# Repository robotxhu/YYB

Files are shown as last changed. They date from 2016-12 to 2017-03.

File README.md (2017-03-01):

# 机器人足球协会摇摇棒PCB

@(机器人足球协会)[摇摇棒|Arduino|电子制作]

**摇摇棒**是一款基于arduino nano 的电子小制作，主要用于机器人足球协会期末制作，在整个制作过程中历经三代开发，从第一版需要额外购买下载器和使用一节锂电池，到第二版更换为两节7号电池，和添加 `CH340G` 去掉下载器。第三版添加自动下载功能，修正以上两版三极管的错误使用，预留晶振焊盘，`CH340G`和`CH340B`可通用。
 
- **加深arduino理解** ：协会成员对arduino的理解
- **锻炼焊接技术** ：锻炼协会成员的焊工
- **炫酷的灯光效果** ：通过编程创造炫酷的灯光效果

-------------------

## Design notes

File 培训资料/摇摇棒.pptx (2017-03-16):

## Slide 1

摇摇棒

机器人足球协会

Happiness is about having each tiny wish come true.

Z_Q

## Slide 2

出场秀

程序&数据

Teach you how to add your images into the board and how to make images

Show you some images

CONTENTS

Show the board how to work

原理图

Now ! show you heart

个人秀

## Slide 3

01

Part One

机足

摇摇棒演示

检测摇摇棒是否正常工作

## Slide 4

02

Part Two

机足

原理图

Click me to find the treasure

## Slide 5

03

Part Three

机足

修改示例程序

There is a great software open the demo

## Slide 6

04

Part Four

Last

Let me see your lights

Use your hands to create beautiful things

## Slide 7

THANK Y U

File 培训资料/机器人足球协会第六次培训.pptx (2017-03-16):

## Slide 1

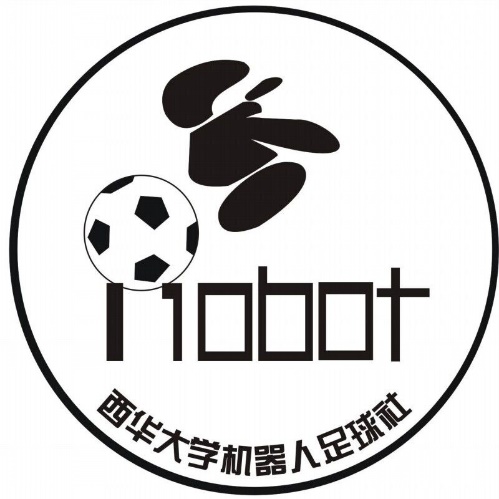
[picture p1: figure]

机器人足球协会第六次培训

Arduino与Processing互动编程

## processing简单入门

- Processing是一种具有革命前瞻性的新兴计算机语言，它的概念是在电子艺术的环境下介绍程序语言，并将电子艺术的概念介绍给程序设计师 (http://baike.baidu.com/view/170222.htm)。它是 Java 语言的延伸，并支持许多现有的 Java 语言架构，不过在语法 (syntax) 上简易许多，并具有许多贴心及人性化的设计。Processing 可以在 Windows、MAC OS X、MAC OS 9 、Linux 等操作系统上使用。

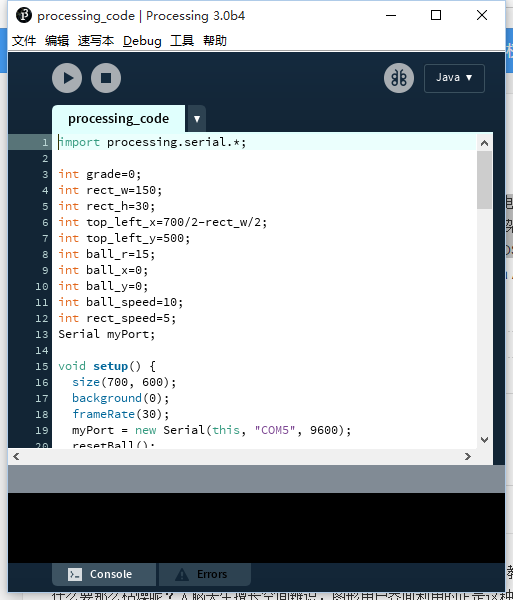
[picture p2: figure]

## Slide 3

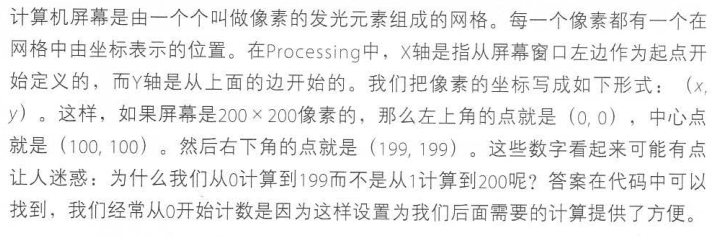
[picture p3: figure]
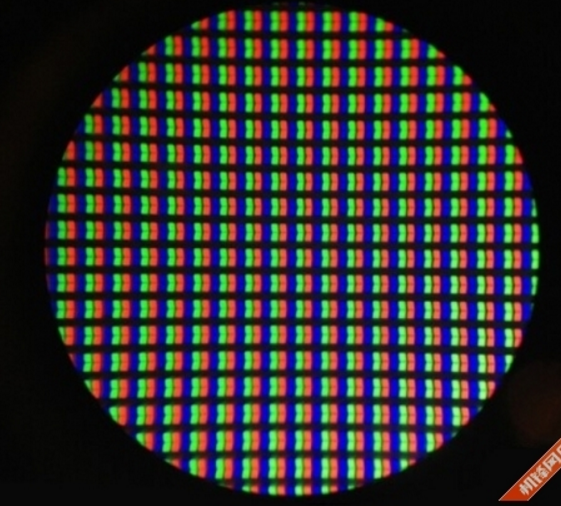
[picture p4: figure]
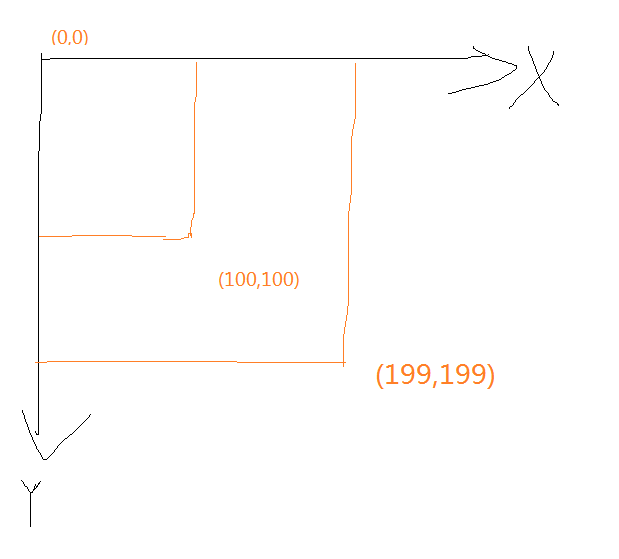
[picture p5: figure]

## 灰度颜色原理

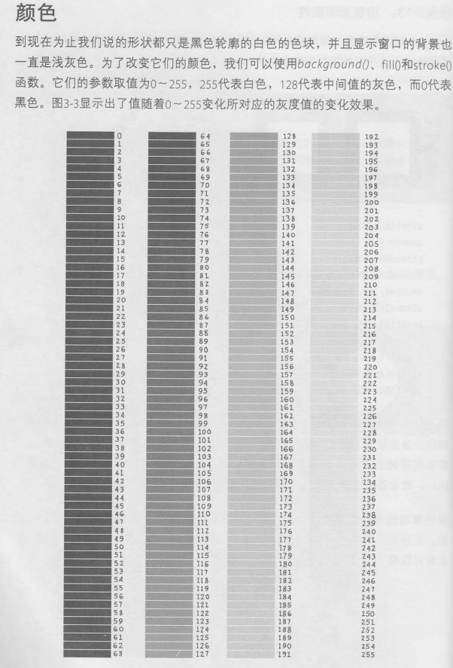
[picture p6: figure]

## 彩色绘图原理-------三基色原理

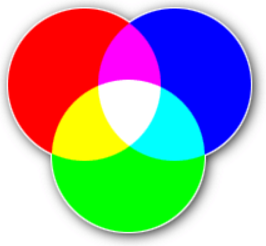
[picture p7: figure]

红绿蓝三基色

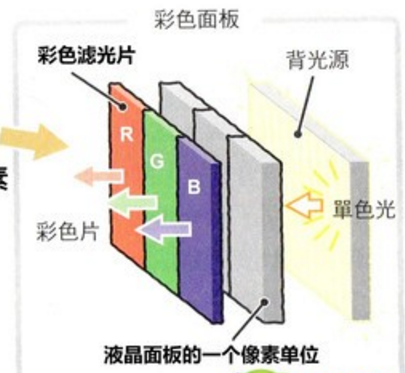
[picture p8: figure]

液晶显示原理

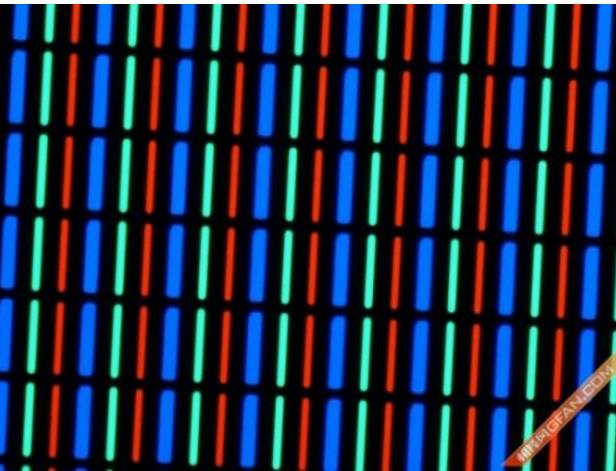
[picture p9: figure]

显示器放大像素点

## 画图原理

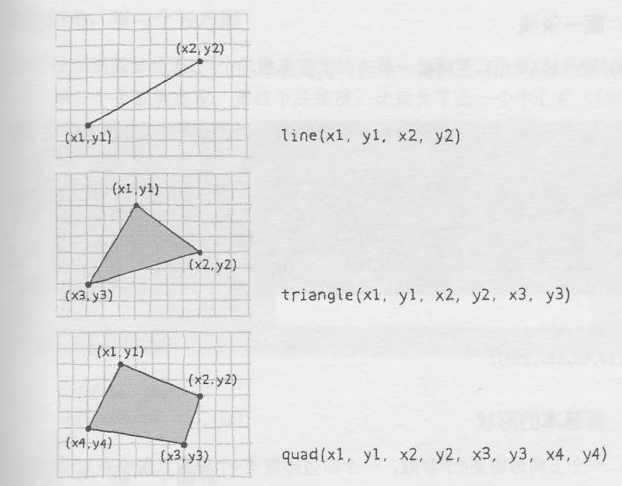
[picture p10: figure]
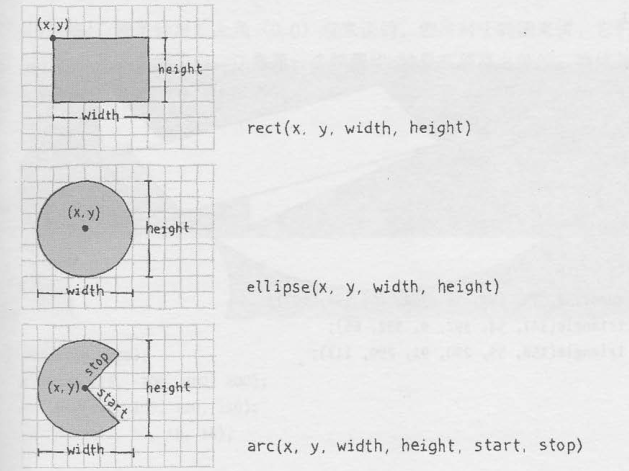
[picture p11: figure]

## 绘图函数

- size(200, 100); //设置窗口大小
- width，height //窗口的大小，无需定义可以直接使用
- background(color); //设置背景的颜色
- fill(color); //设置填充颜色
- random(a,b)； //产生a~b的随机数

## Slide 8

- ellipse(a, b, c, d)； //画椭圆函数
- a float: 圆心x坐标
- b float:圆心y坐标
- c float: 椭圆的宽度d float: 椭圆的高度

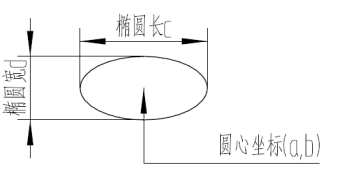
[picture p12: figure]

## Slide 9

- rect(a, b, c, d)； //绘制矩形函数
- a float: 矩阵左上角的x坐标
- b float:矩阵左上角的y坐标
- c float: 矩形的宽度
- d float: 矩形高度

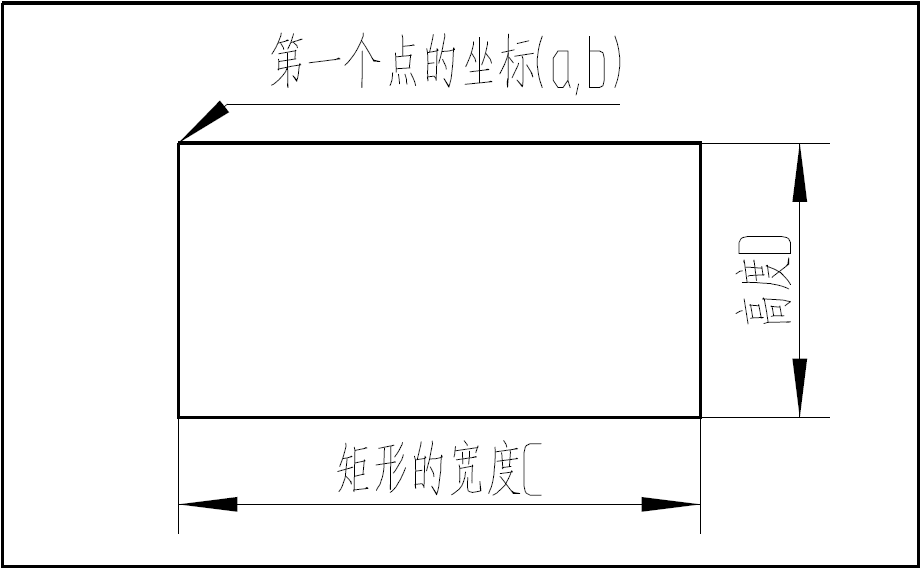
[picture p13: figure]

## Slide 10

- 显示文字
- textSize(32); //设置字体大小
- text(String, x, y);
- String : 要显示的字符串
- x,y:文字的位置坐标

## Processing和单片机通讯语句

- processing串口通信
- import processing.serial.*; //就像c语言里添加头文件
- Serial myPort; //定义一个串口；
- myPort = new Serial(this, “COM*”, 9600); //串口初始化
- myPort.available() //检测串口是否有数据要接收
- command = myPort.read(); //接收数据，存入到 command中

## processing串口示例代码

- import processing.serial.*;
- Serial myPort;
- void setup(){
  - myPort = new Serial(this, "COM5", 9600);
- }
- void draw(){
  - if (myPort.available()>0){
    - int command = myPort.read();
    - println(command);
  - }
- }

## arduino串口使用

- Serial.begain(9600);//初始化串口，设置通信速度为9600
- Serial.print(value); //发送数据value
- a=Serial.read(); //接收数据，并返回的a中
- Serial.available(); //判断是否有数据需要接收

int incomingByte = 0; // for incoming serial data
void setup() {
Serial.begin(9600); // opens serial port, sets data rate to 9600 bps
}
void loop() { // send data only when you receive data:
if (Serial.available() > 0) {
incomingByte = Serial.read(); // read the incoming byte:
Serial.print("I received: "); // say what you got:
Serial.println(incomingByte, DEC);
}
}

## 打印D2口返回的数据

- int a;
- void setup(){
  - pinMode(2,INPUT);
  - Serial.begin(9600);
- }
- void loop(){
  - a=digitalRead(2);
  - Serial.println(a);
- }

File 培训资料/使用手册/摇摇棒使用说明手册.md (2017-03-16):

#摇摇棒使用说明手册
[TOC]
##原理图


##代码调试
###流水灯
>通过流水灯代码的调试，可观察到三十二个灯顺序循环闪烁，同时可以检查摇摇棒是否正常工作。
```cpp
void setup() {
  // 初始化引脚
  for (int i = 2; i < 14; i++)
  {
    pinMode(i, OUTPUT);
  }
}

void loop() {
  // 全亮测试
  for (int i = 2; i < 14; i++)
  {
    digitalWrite(i, LOW);
  }
  // 延时
  delay(5000);
  // 全灭后再流水灯测试
  for (int i = 10; i < 14; i++)
  {
    digitalWrite(i, HIGH);
  }
  // 流水灯测试
  for (char i = 13; i >= 10; i--)
  {
    digitalWrite(i, LOW);
    for (char t = 2; t < 10; t++)
    {
      digitalWrite(t, LOW );
      delay(500);
      digitalWrite(t, HIGH );
    }
    digitalWrite(i, HIGH);
  }
}
```
###取模软件使用
>下载取模软件*PCtoLCD2002*，按照下图进行相应配置。主界面中文本框内的十六进制数组便是取出的字模。

>配置字高和字宽 点击齿轮图标 进入配置字模界面

>配置字模软件

>复制方框中的数据到yybqm.h中数组中

###显示字符
>1、改变 MAX_FRAEAM的值，有三个画面，MAX_FRAEAM后面值为2，四个画面，值为3以此类推。2、在switch case里面按照前面的格式添加一个新的case。3、yybqm.h中新建一个数组，在将之前在取模软件取好的模复制粘贴到yybqm.h中新建的数组里面。注意改变logo 。
```cpp

#include "yybqm.h"
#define DELAY_US 15
int frame = 0, x = 0, y = 0, len = 0;
char MAX_FRAEAM = 2;
void led(const char  a);
void displays(const char  b[]/*,int len*/);
void DELAY(int ms);

void setup() {
  pinMode(A1, INPUT_PULLUP);
  pinMode(A0, INPUT);
  // 初始化引脚
  for (int i = 2; i < 14; i++) {
    pinMode(i, OUTPUT);
    digitalWrite(i, HIGH);
  }
}

void frame_select() {
  DELAY(8);
  digitalRead(A0) == LOW ? frame ++  : frame = frame;
  frame > 2 ? frame = 0 : frame = frame;
}

void state() {
  DELAY(2);
  digitalWrite(A1, LOW);
}

void loop() {
  if (digitalRead(A1)) {
    switch (frame) {
      case 0:
        len = sizeof(logo1) / sizeof(logo1[0]);
        displays(logo1);
        break;
      case 1:
        len = sizeof(logo2) / sizeof(logo2[0]);
        displays(logo2);
        break;
      case 2:
        len = sizeof(logo3) / sizeof(logo3[0]);
        displays(logo3);
        break;
      default:
        len = sizeof(logo1) / sizeof(logo1[0]);
        displays(logo1);
    }
  }
  state();
  frame_select();
}

void led(const char  a) {
  for (int i = 2; i < 10; i++) {
    digitalWrite(i, bitRead(a, 9 - i));
  }
}

void displays(const char  b[]) {
  if (digitalRead(A1) == HIGH) {
    delay(20);
    if (digitalRead(A1) == HIGH) {
      for (x = 0; x < len ; x += 4) {
        for (y = 3; y >= 0; y--) {
          led(pgm_read_byte(&(b[x - y + 3 ])));
          digitalWrite(y + 10, LOW);
          delayMicroseconds(DELAY_US);
          digitalWrite(y + 10, HIGH);
        }
      }
    }
  }
}

void DELAY(int ms) {
  while (ms--) {
    for (int i = 0; i < 330; i++) {}
  }
}
```
>点击IDE的右上角箭头三角形，新建标签，以yybqm.h为名的头文件。
```cpp
#include <avr/pgmspace.h>

const char logo1[] PROGMEM = {     /*机器人足球*/
  0xFF, 0xFF, 0xFF, 0xFF, 0xFF, 0xFF, 0xFF, 0xFF, 0xFF, 0xFF, 0xFF, 0xFF, 0xFF, 0xFF, 0xFF, 0xFF,
  0xFF, 0xFF, 0xFF, 0xFF, 0xFF, 0xFF, 0xFF, 0xFF, 0xFF, 0xFF, 0xFF, 0xFF, 0xFF, 0xFF, 0xFF, 0xFF,
  0xFF, 0xFF, 0xFF, 0xFF, 0xFF, 0xFF, 0xFF, 0xFF, 0xFF, 0xFF, 0xFF, 0xFF, 0xFF, 0xFF, 0xFF, 0xFF,
  0xFF, 0xFF, 0xFF, 0xFF, 0xFF, 0xFF, 0xFF, 0xFF, 0xFF, 0xFF, 0xFF, 0xFF, 0xFF, 0xFF, 0xFF, 0xFF, /*" ",0*/
   0xFF, 0xFF, 0xFF, 0xFF, 0xFF, 0xFF, 0xFF, 0xFF, 0xFF, 0xFF, 0xFF, 0xFF, 0xFF, 0xFF, 0xFF, 0xFF,
  0xFF, 0xFF, 0xFF, 0xFF, 0xFF, 0xFF, 0xFF, 0xFF, 0xFF, 0xFF, 0xFF, 0xFF, 0xFF, 0xFF, 0xFF, 0xFF,
  0xFF, 0xFF, 0xFF, 0xFF, 0xFF, 0xFF, 0xFF, 0xFF, 0xFF, 0xFF, 0xFF, 0xFF, 0xFF, 0xFF, 0xFF, 0xFF,
  0xFF, 0xFF, 0xFF, 0xFF, 0xFF, 0xFF, 0xFF, 0xFF, 0xFF, 0xFF, 0xFF, 0xFF, 0xFF, 0xFF, 0xFF, 0xFF, /*" ",0*/

  0xFF, 0xFF, 0xFF, 0xFF, 0xFF, 0xFF, 0xFF, 0x7F, 0xFF, 0xDF, 0xFE, 0x7F, 0xFF, 0xDF, 0xF8, 0xFF,
  0xFF, 0xDF, 0xC1, 0xFF, 0xFF, 0xDF, 0x07, 0xFF, 0xFF, 0xD0, 0x1F, 0xFF, 0xC0, 0x00, 0x00, 0x01,
  0xC0, 0x00, 0x00, 0x01, 0xE0, 0x00, 0x00, 0x03, 0xFF, 0xDE, 0xFF, 0xFB, 0xFF, 0x9E, 0x3F, 0xF3,
  0xFF, 0x9E, 0x1F, 0xE7, 0xFF, 0xDF, 0x1F, 0x8F, 0xFF, 0xFF, 0xFC, 0x1F, 0xF0, 0x00, 0x00, 0x3F,
  0xF0, 0x00, 0x00, 0xFF, 0xF8, 0x00, 0x07, 0xFF, 0xFB, 0xFF, 0xFF, 0xFF, 0xFB, 0xFF, 0xFF, 0xFF,
  0xFB, 0xFF, 0xFF, 0xFF, 0xFB, 0xFF, 0xFF, 0xFF, 0xFB, 0xFF, 0xFF, 0xFF, 0xF0, 0x00, 0x00, 0x07,
  0xF0, 0x00, 0x00, 0x07, 0xF8, 0x00, 0x00, 0x07, 0xFB, 0xFF, 0xFF, 0xE7, 0xFF, 0xFF, 0xFF, 0xE7,
  0xFF, 0xFF, 0xFE, 0x07, 0xFF, 0xFF, 0xFE, 0x07, 0xFF, 0xFF, 0xFF, 0xC7, 0xFF, 0xFF, 0xFF, 0xEF, /*"机",1*/

  0xFF, 0xFF, 0xFF, 0xFF, 0xFF, 0xFF, 0xFD, 0xFF, 0xFF, 0xFD, 0xFD, 0xFF, 0xFF, 0xFD, 0xF9, 0xFF,
  0xFF, 0xFD, 0xFB, 0xFF, 0xFF, 0xFD, 0xF3, 0xFF, 0xF0, 0x0D, 0xF0, 0x03, 0xF0, 0x0D, 0xE0, 0x03,
  0xF7, 0xBD, 0xE0, 0x07, 0xF7, 0xBD, 0xCB, 0xEF, 0xF7, 0xBD, 0x8B, 0xEF, 0xF7, 0xBD, 0x1B, 0xEF,
  0xF0, 0x1C, 0x3B, 0xEF, 0xE0, 0x18, 0x70, 0x07, 0xE0, 0x00, 0xF0, 0x07, 0xF7, 0xE1, 0xFB, 0xFF,
  0xFF, 0xE5, 0xFF, 0xFF, 0xFF, 0xFD, 0xF8, 0x03, 0xF0, 0x1C, 0xF8, 0x03, 0xF0, 0x1C, 0x78, 0x03,
  0xF0, 0x0D, 0x3B, 0xEF, 0xF7, 0xA5, 0x1B, 0xEF, 0xF7, 0xA1, 0x8B, 0xEF, 0xF7, 0xB1, 0xCB, 0xEF,
  0xF0, 0x11, 0xC0, 0x03, 0xE0, 0x1D, 0xE0, 0x03, 0xE0, 0x19, 0xE0, 0x07, 0xF7, 0xF1, 0xE3, 0xFF,
  0xFF, 0xF1, 0xF3, 0xFF, 0xFF, 0xF9, 0xF3, 0xFF, 0xFF, 0xFD, 0xF7, 0xFF, 0xFF, 0xFF, 0xFF, 0xFF, /*"器",2*/

  0xFF, 0xFF, 0xFF, 0xFF, 0xFF, 0xFF, 0xFF, 0xFF, 0xFF, 0xFF, 0xFF, 0xFD, 0xFF, 0xFF, 0xFF, 0xF9,
  0xFF, 0xFF, 0xFF, 0xFB, 0xFF, 0xFF, 0xFF, 0xF3, 0xFF, 0xFF, 0xFF, 0xE7, 0xFF, 0xFF, 0xFF, 0xCF,
  0xFF, 0xFF, 0xFF, 0x8F, 0xFF, 0xFF, 0xFE, 0x1F, 0xFF, 0xFF, 0xFC, 0x3F, 0xFF, 0xFF, 0xF0, 0x7F,
  0xFF, 0xFF, 0x00, 0xFF, 0xFF, 0xC0, 0x03, 0xFF, 0xC0, 0x00, 0x0F, 0xFF, 0xC0, 0x00, 0x7F, 0xFF,
  0xE0, 0x0F, 0xFF, 0xFF, 0xE4, 0x00, 0x7F, 0xFF, 0xFF, 0xE0, 0x1F, 0xFF, 0xFF, 0xFE, 0x07, 0xFF,
  0xFF, 0xFF, 0xC1, 0xFF, 0xFF, 0xFF, 0xF0, 0x7F, 0xFF, 0xFF, 0xF8, 0x3F, 0xFF, 0xFF, 0xFE, 0x1F,
  0xFF, 0xFF, 0xFF, 0x0F, 0xFF, 0xFF, 0xFF, 0x87, 0xFF, 0xFF, 0xFF, 0xC3, 0xFF, 0xFF, 0xFF, 0xC3,
  0xFF, 0xFF, 0xFF, 0xE3, 0xFF, 0xFF, 0xFF, 0xE7, 0xFF, 0xFF, 0xFF, 0xF7, 0xFF, 0xFF, 0xFF, 0xF7, /*"人",3*/

  0xFF, 0xFF, 0xFF, 0xFF, 0xFF, 0xFF, 0xFF, 0xFF, 0xFF, 0xFF, 0xFF, 0xFD, 0xFF, 0xFF, 0xFF, 0xF1,
  0xFF, 0xFF, 0xFF, 0xE3, 0xFF, 0xFF, 0xFF, 0x0F, 0xFF, 0xFF, 0xFC, 0x1F, 0xFF, 0xFF, 0xC0, 0x3F,
  0xE0, 0x03, 0x80, 0xFF, 0xE0, 0x03, 0x80, 0xFF, 0xE0, 0x03, 0xCE, 0x7F, 0xEF, 0xF7, 0xFF, 0x3F,
  0xEF, 0xF7, 0xFF, 0x9F, 0xEF, 0xF7, 0xFF, 0xCF, 0xEF, 0xF7, 0xFF, 0xCF, 0xEF, 0xF0, 0x00, 0x07,
  0xEF, 0xF0, 0x00, 0x07, 0xEF, 0xF0, 0x00, 0x07, 0xEF, 0xF7, 0xEF, 0xE7, 0xEF, 0xF7, 0xEF, 0xE3,
  0xEF, 0xF7, 0xEF, 0xE3, 0xEF, 0xF7, 0xEF, 0xF3, 0xEF, 0xF7, 0xEF, 0xF3, 0xC0, 0x03, 0xEF, 0xF3,
  0xC0, 0x03, 0xCF, 0xF3, 0xEF, 0xFF, 0xCF, 0xF3, 0xFF, 0xFF, 0xCF, 0xF3, 0xFF, 0xFF, 0xEF, 0xF3,
  0xFF, 0xFF, 0xFF, 0xF3, 0xFF, 0xFF, 0xFF, 0xE7, 0xFF, 0xFF, 0xFF, 0xEF, 0xFF, 0xFF, 0xFF, 0xEF, /*"足",4*/

  0xFF, 0xFF, 0xFF, 0xFF, 0xFF, 0xFF, 0xFF, 0xBF, 0xFD, 0xFE, 0xFF, 0x9F, 0xFD, 0xFE, 0xFF, 0x9F,
  0xFD, 0xFE, 0xFF, 0x1F, 0xFD, 0xFE, 0xFF, 0x3F, 0xFC, 0x00, 0x00, 0x3F, 0xFC, 0x00, 0x00, 0x7F,
  0xFC, 0x00, 0x00, 0x7F, 0xFD, 0xFE, 0xFE, 0xFF, 0xF9, 0xFC, 0xFC, 0xFF, 0xF9, 0xFC, 0xFD, 0xFF,
  0xF9, 0xBE, 0xF8, 0x7F, 0xFD, 0xBB, 0xFA, 0x7F, 0xFF, 0xB9, 0xFC, 0x7F, 0xFF, 0xB8, 0x78, 0xFF,
  0xFF, 0xBC, 0x79, 0xF7, 0xFF, 0xBC, 0x73, 0xF3, 0xFF, 0xBF, 0xF7, 0xF1, 0xC0, 0x00, 0x00, 0x01,
  0xC0, 0x00, 0x00, 0x03, 0xE0, 0x00, 0x00, 0x03, 0xEF, 0xB0, 0x3F, 0xFF, 0xEF, 0xBE, 0x0F, 0xFF,
  0xE7, 0xBF, 0x03, 0xFF, 0xF3, 0xBE, 0x60, 0xFF, 0xF0, 0xB8, 0xF8, 0x7F, 0xF8, 0x30, 0xFC, 0x3F,
  0xFF, 0x31, 0xFE, 0x3F, 0xFF, 0x3B, 0xFF, 0x3F, 0xFF, 0xBF, 0xFF, 0x7F, 0xFF, 0xFF, 0xFF, 0xFF, /*"球",5*/

  0xFF, 0xFF, 0xFF, 0xFF, 0xFF, 0xFF, 0xFF, 0xFF, 0xFF, 0xFF, 0xFF, 0xFF, 0xFF, 0xFF, 0xFF, 0xFF,
  0xFF, 0xFF, 0xFF, 0xFF, 0xFF, 0xFF, 0xFF, 0xFF, 0xFF, 0xFF, 0xFF, 0xFF, 0xFF, 0xFF, 0xFF, 0xFF,
  0xFF, 0xFF, 0xFF, 0xFF, 0xFF, 0xFF, 0xFF, 0xFF, 0xFF, 0xFF, 0xFF, 0xFF, 0xFF, 0xFF, 0xFF, 0xFF,
  0xFF, 0xFF, 0xFF, 0xFF, 0xFF, 0xFF, 0xFF, 0xFF, 0xFF, 0xFF, 0xFF, 0xFF, 0xFF, 0xFF, 0xFF, 0xFF /*" ",6*/
};

const char logo2[] PROGMEM = {    /*L(0) O(1) V(2) E(3)*/
  0xFF, 0xFF, 0xFF, 0xFF, 0xFD, 0xFF, 0xFF, 0xEF, 0xFD, 0xFF, 0xFF, 0xEF, 0xFD, 0xFF, 0xFF, 0xCF,
  0xFC, 0x00, 0x00, 0x0F, 0xFC, 0x00, 0x00, 0x0F, 0xFC, 0x00, 0x00, 0x0F, 0xFD, 0xFF, 0xFF, 0xCF,
  0xFD, 0xFF, 0xFF, 0xEF, 0xFD, 0xFF, 0xFF, 0xEF, 0xFF, 0xFF, 0xFF, 0xEF, 0xFF, 0xFF, 0xFF, 0xEF,
  0xFF, 0xFF, 0xFF, 0xEF, 0xFF, 0xFF, 0xFF, 0xEF, 0xFF, 0xFF, 0xFF, 0xCF, 0xFF, 0xFF, 0xFF, 0xCF,
  0xFF, 0xFF, 0xFF, 0x8F, 0xFF, 0xFF, 0xFE, 0x0F, 0xFF, 0xFF, 0xFE, 0x1F, 0xFF, 0xFF, 0xFF, 0xFF, /*"L",0*/

  0xFF, 0xFF, 0xFF, 0xFF, 0xFF, 0xFE, 0x1F, 0xFF, 0xFF, 0xE0, 0x03, 0xFF, 0xFF, 0x80, 0x00, 0xFF,
  0xFF, 0x00, 0x00, 0x7F, 0xFE, 0x03, 0xE0, 0x3F, 0xFE, 0x3F, 0xFF, 0x1F, 0xFC, 0xFF, 0xFF, 0x9F,
  0xFC, 0xFF, 0xFF, 0xCF, 0xFD, 0xFF, 0xFF, 0xEF, 0xFD, 0xFF, 0xFF, 0xEF, 0xFD, 0xFF, 0xFF, 0xEF,
  0xFD, 0xFF, 0xFF, 0xCF, 0xFC, 0xFF, 0xFF, 0xDF, 0xFE, 0x7F, 0xFF, 0x1F, 0xFE, 0x0F, 0xFC, 0x1F,
  0xFF, 0x00, 0x00, 0x3F, 0xFF, 0x80, 0x00, 0x7F, 0xFF, 0xE0, 0x01, 0xFF, 0xFF, 0xF8, 0x07, 0xFF, /*"O",1*/

  0xFF, 0xFF, 0xFF, 0xFF, 0xFD, 0xFF, 0xFF, 0xFF, 0xFD, 0xFF, 0xFF, 0xFF, 0xFC, 0x3F, 0xFF, 0xFF,
  0xFC, 0x07, 0xFF, 0xFF, 0xFC, 0x00, 0xFF, 0xFF, 0xFC, 0x00, 0x0F, 0xFF, 0xFD, 0xE0, 0x01, 0xFF,
  0xFF, 0xFE, 0x00, 0x3F, 0xFF, 0xFF, 0xC0, 0x0F, 0xFF, 0xFF, 0xF8, 0x0F, 0xFF, 0xFF, 0xE0, 0x3F,
  0xFF, 0xFF, 0x01, 0xFF, 0xFD, 0xF8, 0x0F, 0xFF, 0xFD, 0xC0, 0x7F, 0xFF, 0xFC, 0x03, 0xFF, 0xFF,
  0xFC, 0x1F, 0xFF, 0xFF, 0xFC, 0xFF, 0xFF, 0xFF, 0xFD, 0xFF, 0xFF, 0xFF, 0xFD, 0xFF, 0xFF, 0xFF, /*"V",2*/

  0xFF, 0xFF, 0xFF, 0xFF, 0xFD, 0xFF, 0xFF, 0xEF, 0xFD, 0xFF, 0xFF, 0xEF, 0xFC, 0x00, 0x00, 0x0F,
  0xFC, 0x00, 0x00, 0x0F, 0xFC, 0x00, 0x00, 0x0F, 0xFC, 0x00, 0x00, 0x0F, 0xFD, 0xFF, 0x7F, 0xEF,
  0xFD, 0xFF, 0x7F, 0xEF, 0xFD, 0xFF, 0x7F, 0xEF, 0xFD, 0xFF, 0x7F, 0xEF, 0xFD, 0xFF, 0x7F, 0xEF,
  0xFD, 0xFE, 0x7F, 0xEF, 0xFD, 0xF0, 0x0F, 0xEF, 0xFC, 0xF0, 0x0F, 0xCF, 0xFC, 0xFF, 0xFF, 0xCF,
  0xFC, 0x7F, 0xFF, 0x8F, 0xFC, 0x1F, 0xFE, 0x0F, 0xFF, 0x1F, 0xFE, 0x3F, 0xFF, 0xFF, 0xFF, 0xFF /*"E",3*/
};

const char  logo3[] PROGMEM = { /*1(0) 2(1) 3(2) 4(3)*/
  0xFF, 0xFF, 0xFF, 0xFF, 0xFF, 0xFF, 0xFF, 0xFF, 0xFF, 0xFF, 0xFF, 0xFF, 0xFF, 0x7F, 0xFF, 0xEF,
  0xFF, 0x7F, 0xFF, 0xEF, 0xFF, 0x7F, 0xFF, 0xEF, 0xFF, 0x7F, 0xFF, 0xCF, 0xFE, 0x00, 0x00, 0x0F,
  0xFC, 0x00, 0x00, 0x0F, 0xFC, 0x00, 0x00, 0x0F, 0xFF, 0xFF, 0xFF, 0xCF, 0xFF, 0xFF, 0xFF, 0xEF,
  0xFF, 0xFF, 0xFF, 0xEF, 0xFF, 0xFF, 0xFF, 0xEF, 0xFF, 0xFF, 0xFF, 0xFF, 0xFF, 0xFF, 0xFF, 0xFF, /*"1",0*/

  0xFF, 0xFF, 0xFF, 0xFF, 0xFF, 0xFF, 0xFF, 0xFF, 0xFF, 0x87, 0xFF, 0x8F, 0xFF, 0x07, 0xFF, 0x0F,
  0xFE, 0x67, 0xFE, 0x4F, 0xFC, 0xFF, 0xFC, 0xCF, 0xFD, 0xFF, 0xF1, 0xCF, 0xFD, 0xFF, 0xE3, 0xCF,
  0xFD, 0xFF, 0xC7, 0xCF, 0xFD, 0xFF, 0x8F, 0xCF, 0xFC, 0xFF, 0x1F, 0xCF, 0xFC, 0x7C, 0x3F, 0xCF,
  0xFE, 0x00, 0x7F, 0x8F, 0xFE, 0x00, 0xFC, 0x0F, 0xFF, 0x83, 0xFC, 0x3F, 0xFF, 0xFF, 0xFF, 0xFF, /*"2",1*/

  0xFF, 0xFF, 0xFF, 0xFF, 0xFF, 0xFF, 0xFF, 0xFF, 0xFF, 0x0F, 0xFC, 0x3F, 0xFE, 0x0F, 0xFC, 0x1F,
  0xFE, 0x0F, 0xFC, 0x1F, 0xFC, 0xFF, 0xFF, 0xCF, 0xFD, 0xFF, 0x7F, 0xEF, 0xFD, 0xFF, 0x7F, 0xEF,
  0xFD, 0xFF, 0x7F, 0xEF, 0xFC, 0xFE, 0x3F, 0xEF, 0xFC, 0x7C, 0x3F, 0xCF, 0xFE, 0x00, 0x9F, 0x9F,
  0xFF, 0x01, 0x80, 0x1F, 0xFF, 0x83, 0xC0, 0x3F, 0xFF, 0xFF, 0xF0, 0xFF, 0xFF, 0xFF, 0xFF, 0xFF, /*"3",2*/

  0xFF, 0xFF, 0xFF, 0xFF, 0xFF, 0xFF, 0xF3, 0xFF, 0xFF, 0xFF, 0xC3, 0xFF, 0xFF, 0xFF, 0x8B, 0xFF,
  0xFF, 0xFE, 0x1B, 0xFF, 0xFF, 0xF8, 0x7B, 0xFF, 0xFF, 0xF1, 0xFB, 0xEF, 0xFF, 0xC7, 0xFB, 0xEF,
  0xFF, 0x0F, 0xFB, 0xEF, 0xFC, 0x00, 0x00, 0x0F, 0xFC, 0x00, 0x00, 0x0F, 0xFC, 0x00, 0x00, 0x0F,
  0xFF, 0xFF, 0xFB, 0xEF, 0xFF, 0xFF, 0xFB, 0xEF, 0xFF, 0xFF, 0xFB, 0xEF, 0xFF, 0xFF, 0xFF, 0xFF /*"4",3*/
};
```

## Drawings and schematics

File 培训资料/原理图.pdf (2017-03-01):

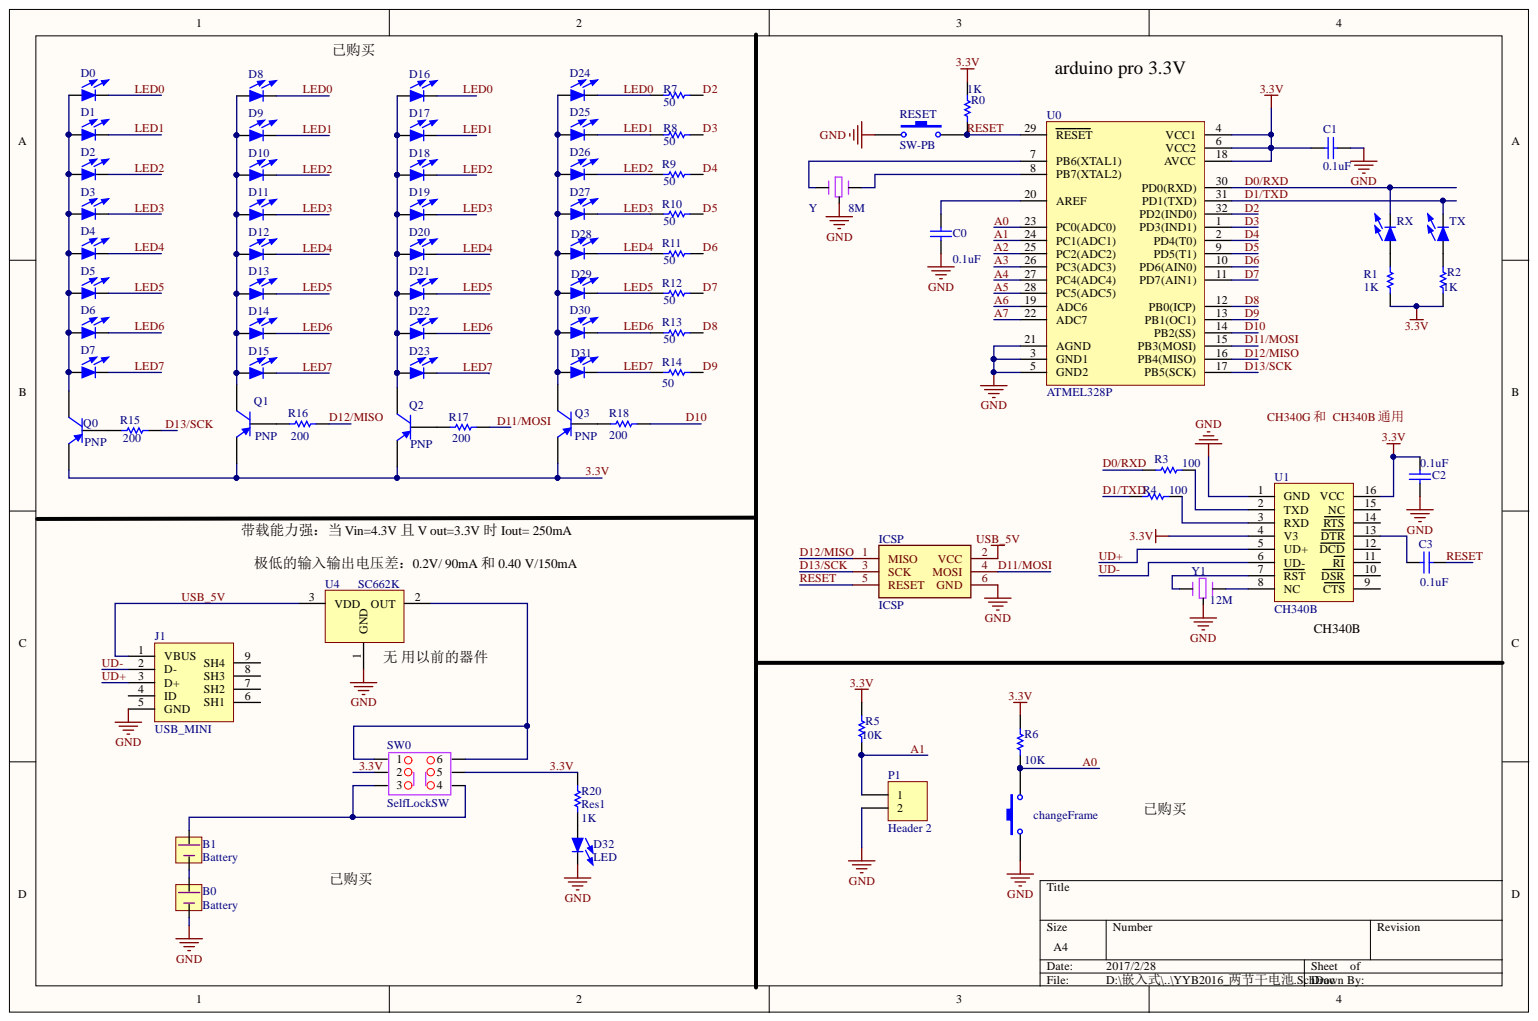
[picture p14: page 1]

带载能力强：当 Vin=4.3V 且 V out=3.3V 时 Iout= 250mA

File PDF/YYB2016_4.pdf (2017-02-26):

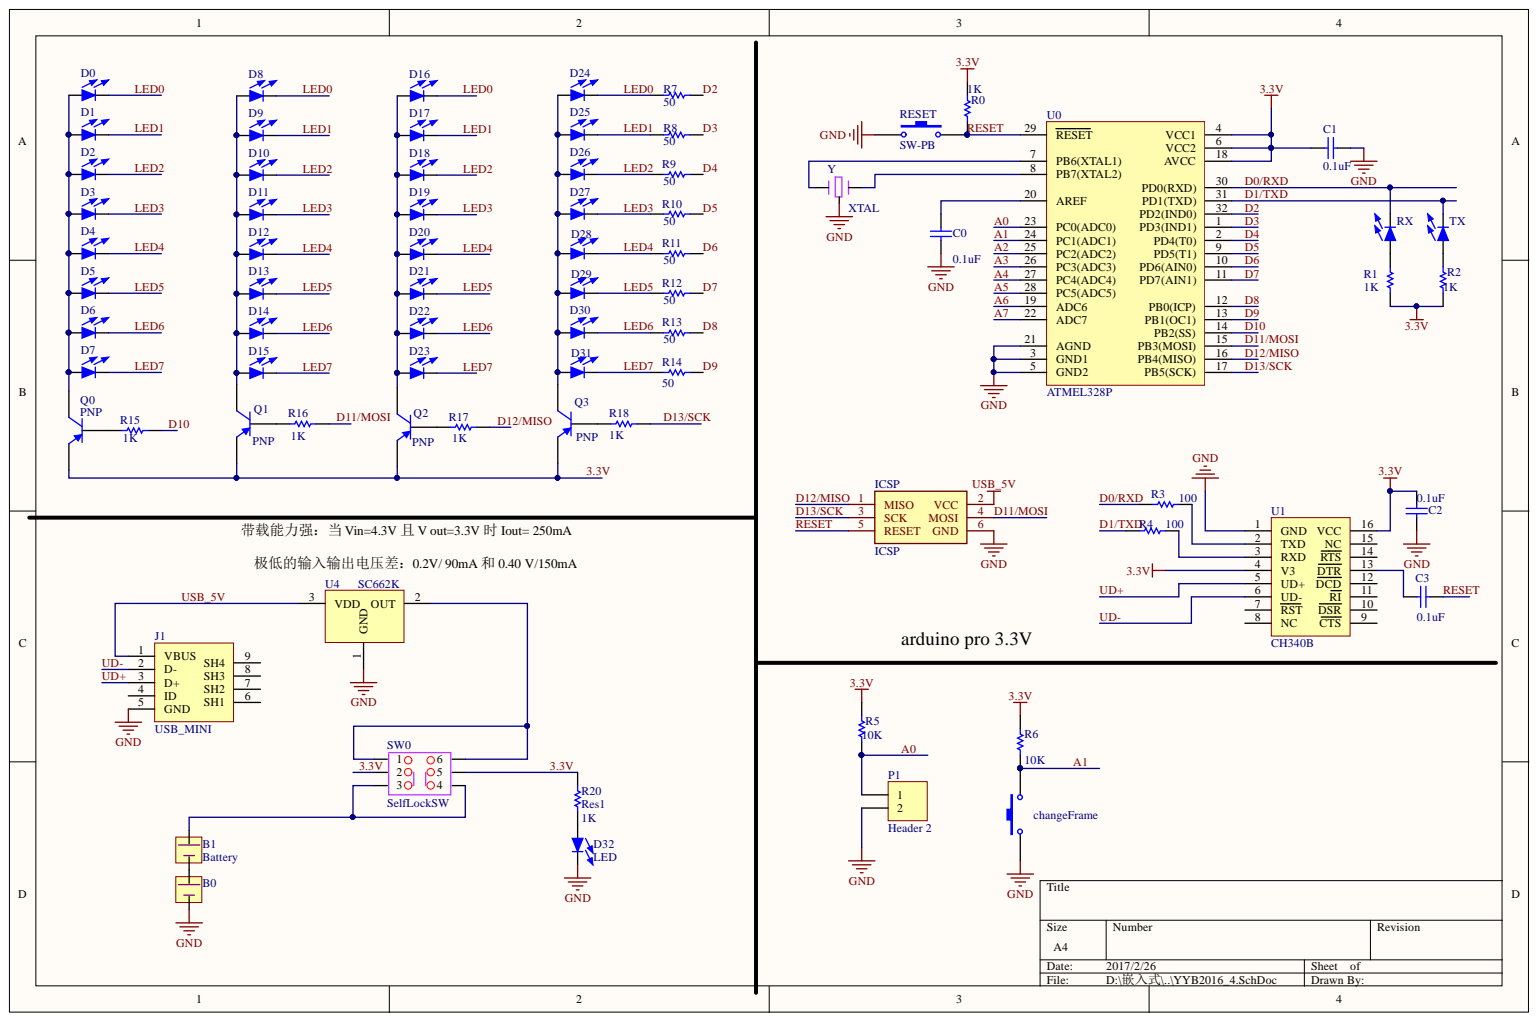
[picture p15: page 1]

带载能力强：当 Vin=4.3V 且 V out=3.3V 时 Iout= 250mA

UD+ | UD- 6
UD- | RST 7

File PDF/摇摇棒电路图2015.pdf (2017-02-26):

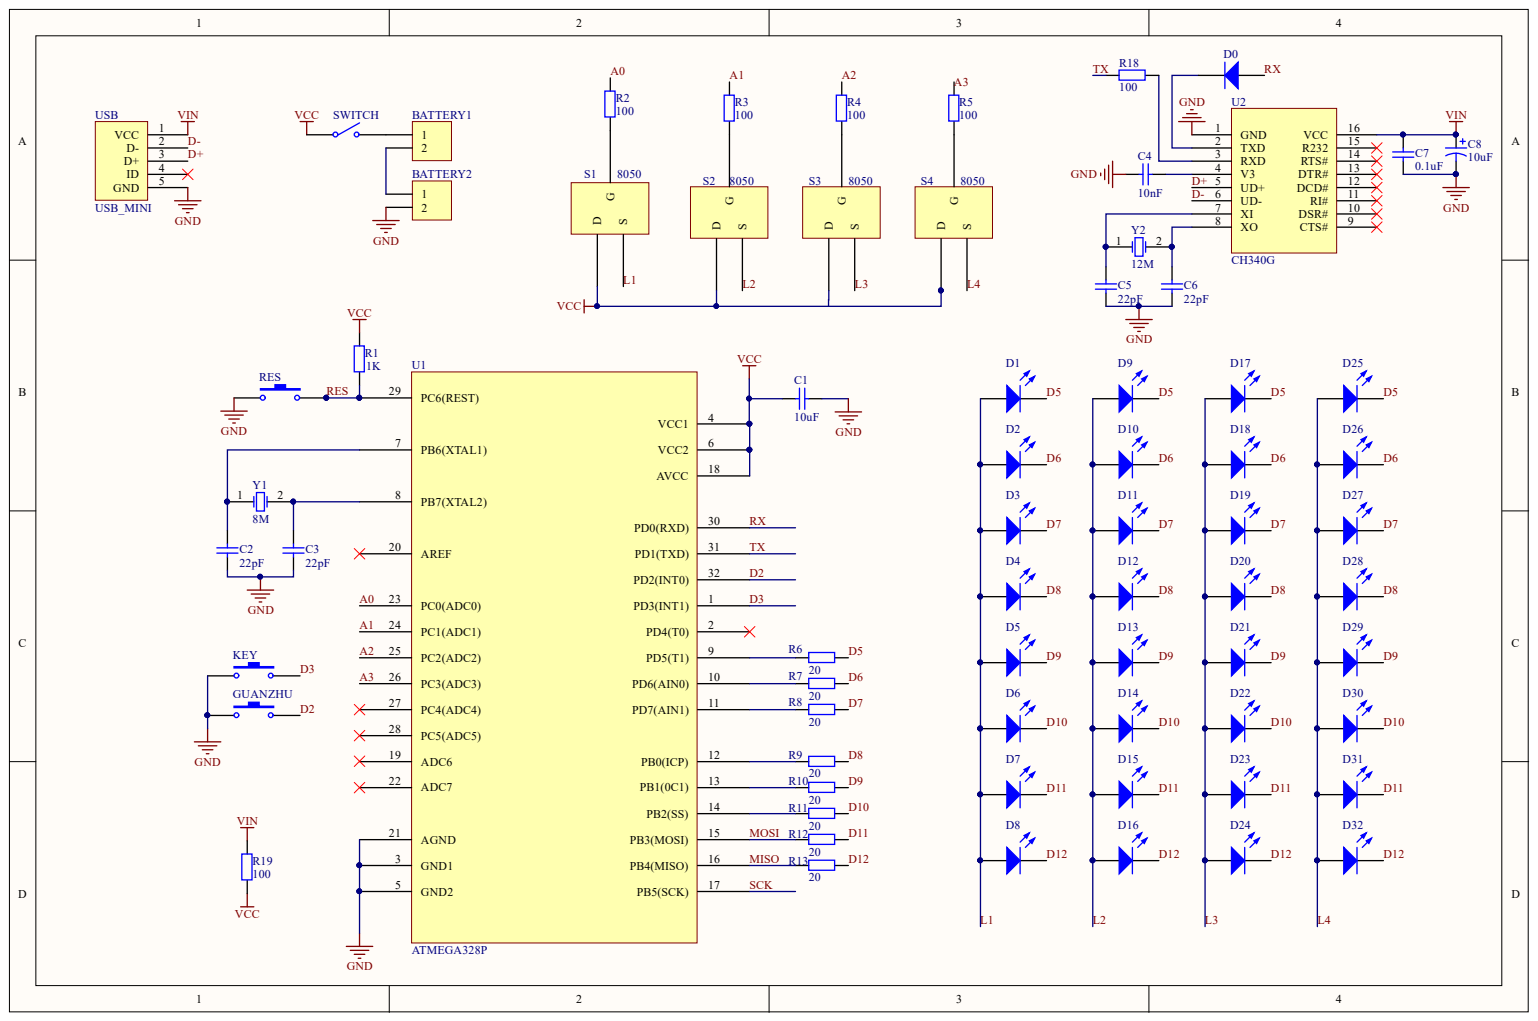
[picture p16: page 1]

PB7(XTAL2) 8

AREF 20

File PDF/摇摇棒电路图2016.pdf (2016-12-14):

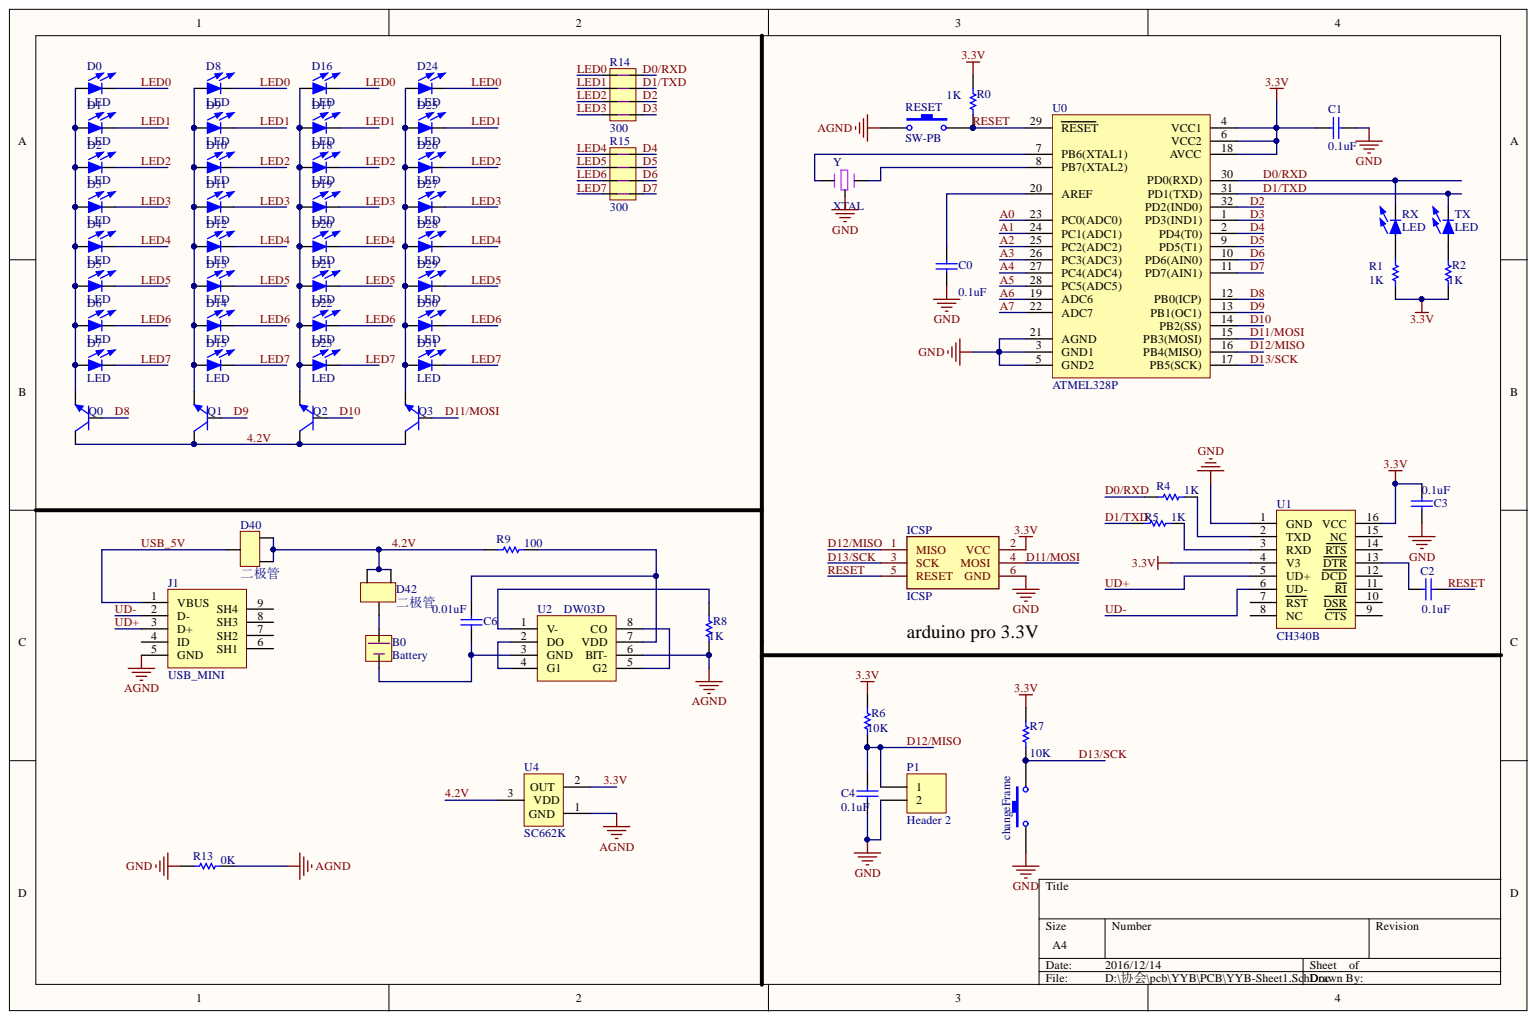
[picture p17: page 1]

1 | DO 2 GN | 5 BIT-6 VDD 7 CO 8

3 | D G 1 G 2

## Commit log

2017-02-22 xk2304 merge
    [YYB-PCB1.PcbDoc, YYB-PCB2.PcbDoc, YYB-Sheet1.SchDoc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]
2017-02-26 电源重新设计-去掉多余器件，简化设计
    [YYB-PCB1.PcbDoc, YYB-PCB2.PcbDoc, YYB-Sheet1.SchDoc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]
2017-02-27 layout over with out led
    [YYB2016_两节干电池.SchDoc, YYB_2016_2.PcbDoc, YYB_Project1.PrjPcb]
2017-03-16 培训资料
    [YYB2016_两节干电池.SchDoc, YYB_2016_2.PcbDoc, YYB_Project1.PrjPcb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]
2017-05-28 add new version
    [YYB2016_两节干电池.SchDoc, YYB_2016_2 电源不匹配问题解决.PcbDoc, YYB_2016_2.PcbDoc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]
